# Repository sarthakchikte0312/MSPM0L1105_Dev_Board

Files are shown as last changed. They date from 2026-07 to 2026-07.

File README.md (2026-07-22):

# MSPM0L1105 Dev Board

A custom development/breakout board for Texas Instruments' **MSPM0L1105**, an ultra-low-power Arm Cortex-M0+ microcontroller. Designed in KiCad.

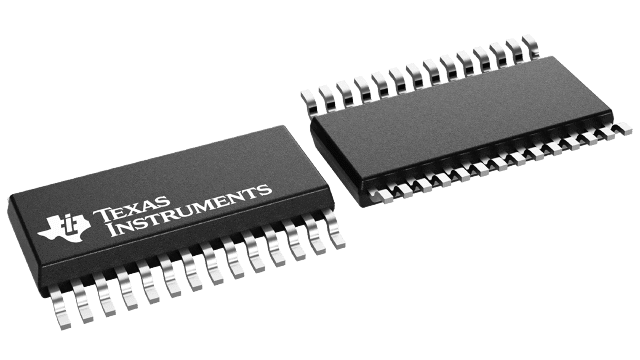
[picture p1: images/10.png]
PCB Render


## Why the MSPM0L1105?

The MSPM0L1105 is part of TI's MSPM0 family, and it's a solid choice for low-power, cost-sensitive embedded designs for a few reasons:

- **Arm Cortex-M0+ core** running up to 32 MHz — enough headroom for real control/sensor tasks while keeping power draw low.
- **Ultra-low-power modes** with fast wake-up, making it well suited for battery-powered or energy-harvesting applications.
- **Integrated analog peripherals** — 12-bit ADC, comparators, and op-amp(s) on many variants — reducing the need for external analog front-end components.
- **Rich communication peripherals** — UART, I2C, SPI — for interfacing sensors, displays, or other MCUs.
- **Low cost and small footprint**, making it attractive for space-constrained or high-volume designs where a full Cortex-M4 is overkill.
- **Common tooling** — MSPM0 shares a peripheral driver library (DriverLib) and code examples across the family, so firmware written here can port to bigger MSPM0 parts (M4-based) with minimal changes if the project scales up.
- Backed by TI's **SysConfig** tool, which simplifies pin muxing and peripheral configuration compared to hand-rolling register setup.

This dev board exists to make it easy to bring up, test, and prototype around the MSPM0L1105 — breaking out its I/O, providing power regulation, and exposing debug headers — before committing the MCU to a larger system design.


```
## Repository Structure

```
mspm0l1105-dev-board/
├── hardware/       KiCad project, schematic, PCB layout, libraries, 3D models
├── docs/           Datasheet, schematic PDF, pinout reference, BOM
├── images/         Board renders and photos
```

## Hardware Overview

| Item | Details |
|---|---|
| MCU | TI MSPM0L1105TDGS28R (Arm Cortex-M0+), VSSOP-28 package |
| Design tool | KiCad 10 |
| Layers | 2-layer, 1.6 mm board thickness |
| Board size | ~124 x 89 mm |
| Power in | USB-C receptacle (J4, USB4085) |
| Regulation | MIC5209-3.3YS LDO (U4) → 3.3V rail, selectable via LDO_JUMPER (J6) |
| USB-to-Serial | CH340K bridge (U2), for UART programming/debug over USB |
| Protection | SRV05-4 TVS array (U3) on USB D+/D− for ESD protection |
| Programming | BSL entry circuit (BSL_TX / BSL_RX / BSL_INVOKE) via Q3 (BC857) + D5/D6 (BAS16), auto-triggered from the USB-serial bridge's DTR/RTS lines |
| Debug | Dedicated 5-pin SWD header (J5): SWDIO / SWCLK / RST |
| Jumpers | J3 (UART-SELECT, 2x5), J6 (LDO_JUMPER), J7 (GND_JUMPER) |
| User I/O | SW1 = RESET, SW2 = BSL_BOOT, SW3 = USER (tied to PA16); D1 = green LED, D2 = blue LED, D4 = red LED |
| I/O broken out | J1 (IO_A) and J2 (IO_B), two 12-pin headers exposing UART0 (TXD/RXD), I2C (SCL/SDA), SPI (SCK/MOSI/MISO/CS1/CS2), TIMG4 capture pins, and GPIOs PA9/PA14/PA15/PA16/PA21/PA25/PA26/PA27 |
| Connectors | J1–J7: two GPIO headers, UART-select header, USB-C, SWD header, LDO and GND jumpers |

Full parts list with values and footprints: [`docs/BOM.csv`](docs/BOM.csv) (58 line items).

## Gerbers / Fabrication Output

This repo was built in **KiCad 10**. To (re)generate fab output, run from the `hardware/` folder with KiCad 9+ installed:

```bash
kicad-cli pcb export gerbers --output ../gerbers/ MSPM0L1105_dev_board.kicad_pcb
kicad-cli pcb export drill   --output ../gerbers/ MSPM0L1105_dev_board.kicad_pcb
```

Then zip the contents of `gerbers/` and upload directly to your fab house (JLCPCB, PCBWay, etc.). If you want, run these locally and drop the output in `gerbers/` before pushing — this sandbox only has KiCad 7 available, which can't open KiCad 10 project files, so it can't generate them for you.

## Getting Started

1. Clone this repo.
2. Open `hardware/MSPM0L1105_dev_board.kicad_pro` in KiCad (version *X.X* or later recommended).
3. Gerbers for the current revision are in `gerbers/` — ready to send to a fab house (JLCPCB, PCBWay, etc.).
4. See `docs/BOM.csv` for the parts list.

## Status

✅ Schematic and PCB layout complete (KiCad 10). Gerbers pending local export (see above) before sending to fab.

## Acknowledgements

- [TI MSPM0L1105 product page](https://www.ti.com/product/MSPM0L1105) for datasheet and reference material.

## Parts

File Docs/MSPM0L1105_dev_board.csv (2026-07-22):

Reference | Value | Footprint | Datasheet | Qty | DNP | Exclude from BOM | Exclude from Board
C1 | 0.47u | User_Global_Library:Cap-Tant-T491A |  | 1
C2 | 10n | Capacitor_SMD:C_0805_2012Metric_Pad1.18x1.45mm_HandSolder |  | 1
C3,C6,C7 | 100n | Capacitor_SMD:C_0805_2012Metric_Pad1.18x1.45mm_HandSolder |  | 3
C4,C8,C9 | 10u | User_Global_Library:Cap-Tant-CaseB |  | 3
C5 | 10n | Capacitor_SMD:C_1210_3225Metric_Pad1.33x2.70mm_HandSolder |  | 1
D1 | GREEN | User_Global_Library:LED_0603_or_0805 |  | 1
D2 | BLUE | User_Global_Library:LED_0603_or_0805 |  | 1
D3 | 1N4001W | User_Global_Library:D_SOD-123-pins12 |  | 1
D4 | RED | User_Global_Library:LED_0603_or_0805 |  | 1
D5,D6 | BAS16 | User_Global_Library:SOT-23-NEW |  | 2
J1 | IO_A | User_Global_Library:PinHeader_1x12_P2.54mm_Vertical |  | 1
J2 | IO_B | User_Global_Library:PinHeader_1x12_P2.54mm_Vertical |  | 1
J3 | UART-SELECT | User_Global_Library:PinHeader_2x5 |  | 1
J4 | USB_C_Receptacle_USB4085 | Connector_USB:USB_C_Receptacle_GCT_USB4085 | https://gct.co/connector/usb4085 | 1
J5 | SWD | User_Global_Library:PinHeader_1x05_P2.54mm_Vertical |  | 1
J6 | LDO_JUMPER | User_Global_Library:PinHeader_1x02_P2.54mm_Vertical |  | 1
J7 | GND_JUMPER | User_Global_Library:PinHeader_1x02_P2.54mm_Vertical |  | 1
Q3 | BC857 | User_Global_Library:SOT-23-NEW |  | 1
R1 | 100k 0.1% | Resistor_SMD:R_0805_2012Metric_Pad1.20x1.40mm_HandSolder |  | 1
R2,R3,R12 | 100R | Resistor_SMD:R_0805_2012Metric_Pad1.20x1.40mm_HandSolder |  | 3
R4,R5,R7,R17 | 100k | Resistor_SMD:R_0805_2012Metric_Pad1.20x1.40mm_HandSolder |  | 4
R8,R9,R25,R26,R27 | 10k | Resistor_SMD:R_0805_2012Metric_Pad1.20x1.40mm_HandSolder |  | 5
R10 | 220R | Resistor_SMD:R_0805_2012Metric_Pad1.20x1.40mm_HandSolder |  | 1
R11 | 820R | Resistor_SMD:R_0805_2012Metric_Pad1.20x1.40mm_HandSolder |  | 1
R13 | 1M | Resistor_SMD:R_1210_3225Metric_Pad1.30x2.65mm_HandSolder |  | 1
R14,R15 | 5.1k | Resistor_SMD:R_0805_2012Metric_Pad1.20x1.40mm_HandSolder |  | 2
R19 | 1k | Resistor_SMD:R_0805_2012Metric_Pad1.20x1.40mm_HandSolder |  | 1
R24 | 47k | Resistor_SMD:R_0805_2012Metric_Pad1.20x1.40mm_HandSolder |  | 1
SW1 | RESET | User_Global_Library:Tact-SW-4x3mm-body |  | 1
SW2 | BSL_BOOT | User_Global_Library:Tact-SW-4x3mm-body |  | 1
SW3 | USER_PA16 | User_Global_Library:Tact-SW-4x3mm-body |  | 1
U1 | MSPM0L1105TDGS28R | User_Global_Library:VSSOP28-DGS-TI |  | 1
U2 | CH340K | User_Global_Library:SSOP-10-1EP_CH340K |  | 1
U3 | SRV05-4 | User_Global_Library:SOT23-6 | http://www.onsemi.com/pub/Collateral/SRV05-4-D.PDF | 1
U4 | MIC5209-3.3YS | User_Global_Library:SOT-223 |  | 1

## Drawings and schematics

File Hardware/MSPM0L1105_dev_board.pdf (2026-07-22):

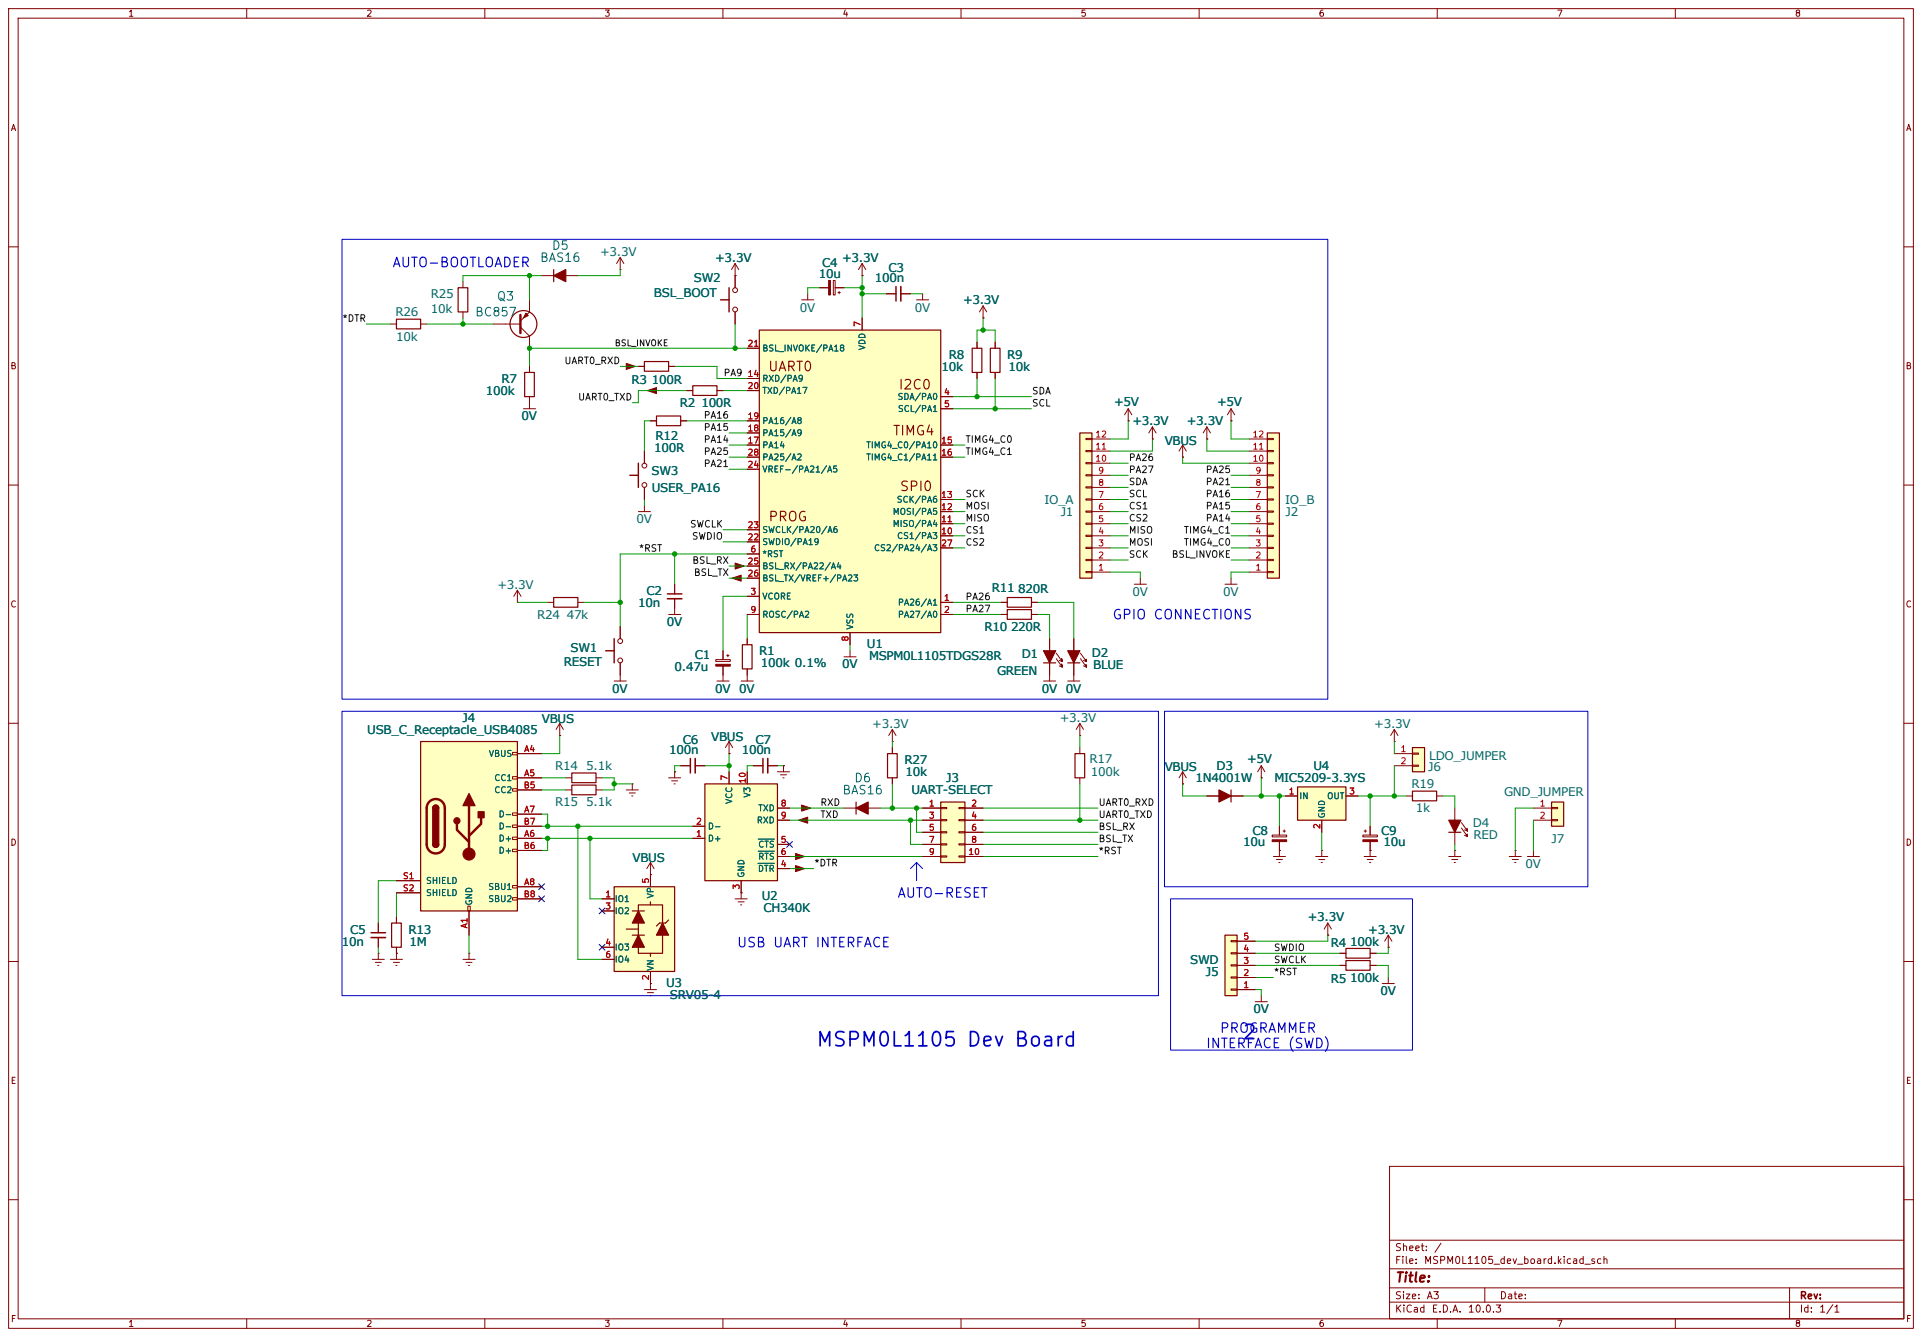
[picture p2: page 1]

3 DTR 4 CTS 5 RTS 6 VCC

SHIELD S1

Size: A3 | Rev: | F Date:
KiCad E.D.A. 10.0.3 | Id: 1/1

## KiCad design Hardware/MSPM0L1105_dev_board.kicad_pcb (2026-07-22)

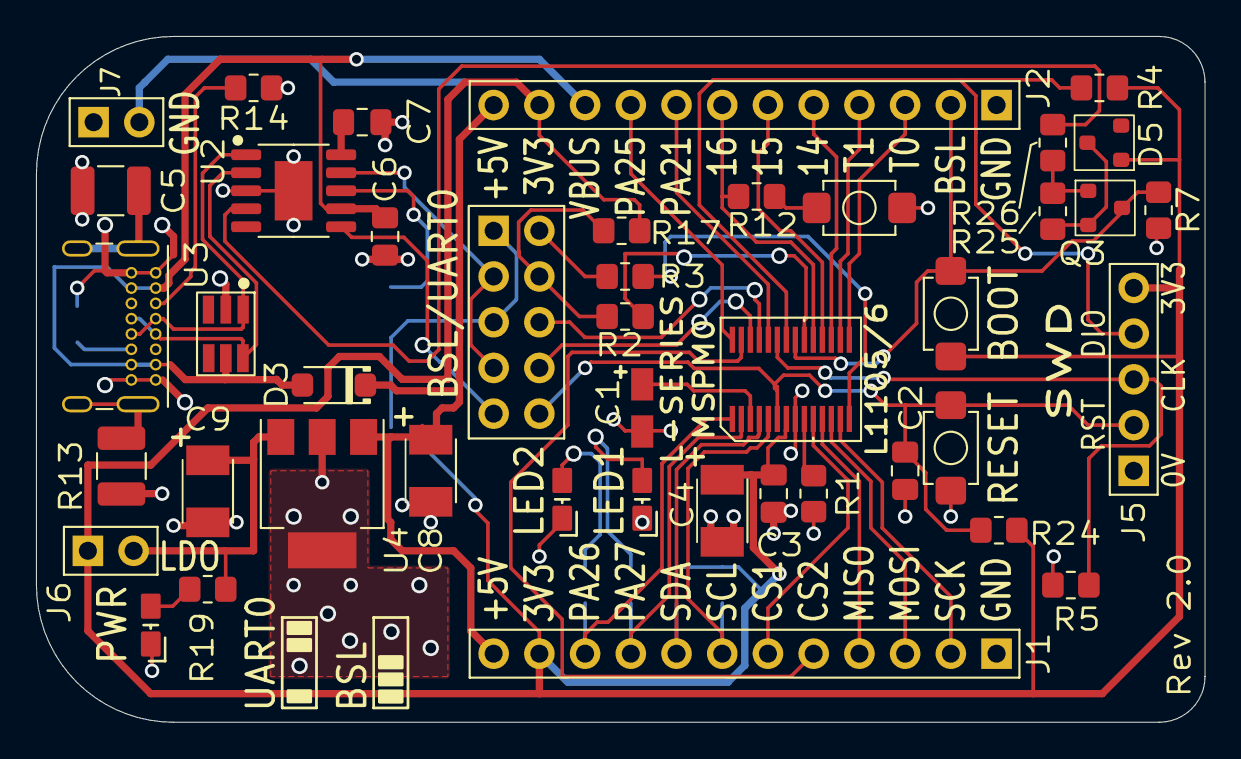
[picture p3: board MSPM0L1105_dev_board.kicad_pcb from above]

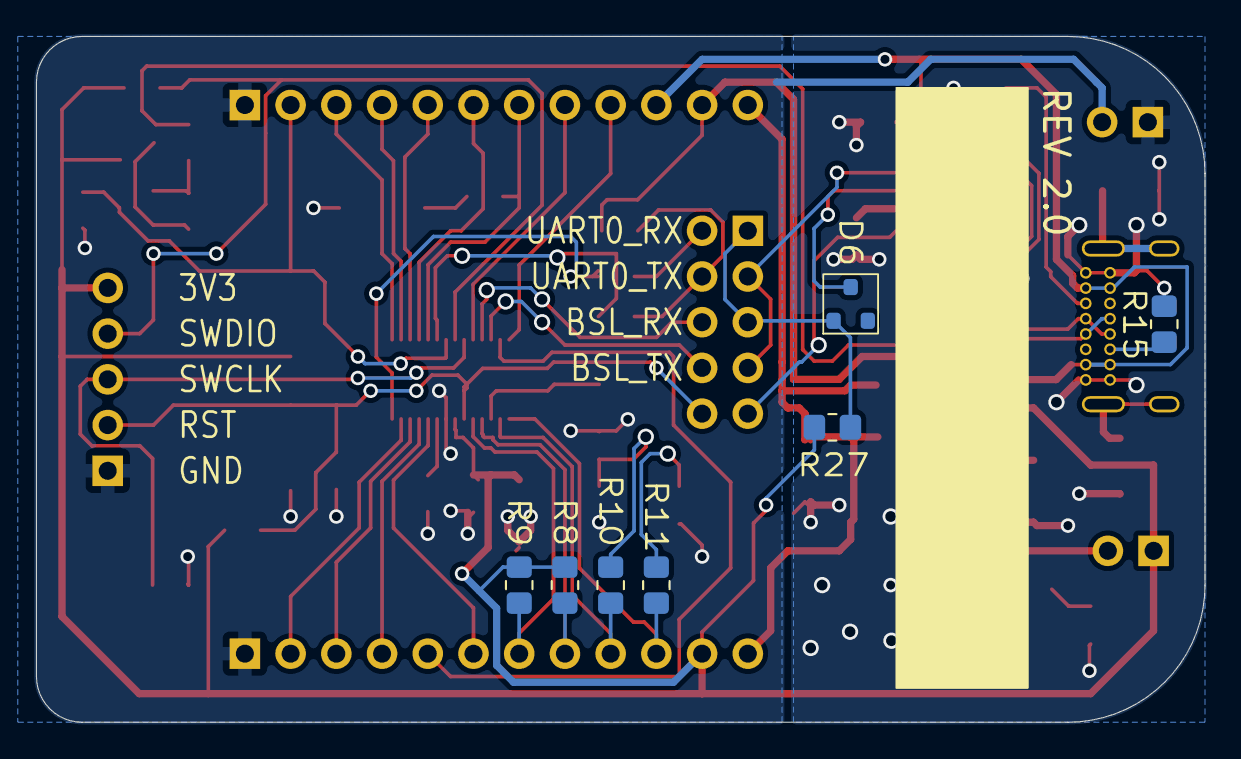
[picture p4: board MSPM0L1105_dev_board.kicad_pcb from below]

Board: 2 copper layers, 64.9 x 38.1 mm, 50 parts (7 on the bottom side), 52 nets.

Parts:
C1: 0.47u; Cap-Tant-T491A
C2: 10n; C_0805_2012Metric_Pad1.18x1.45mm_HandSolder
C3, C6, C7: 100n; C_0805_2012Metric_Pad1.18x1.45mm_HandSolder
C4, C8, C9: 10u; Cap-Tant-CaseB
C5: 10n; C_1210_3225Metric_Pad1.33x2.70mm_HandSolder
D1: GREEN; LED_0603_or_0805
D2: BLUE; LED_0603_or_0805
D3: 1N4001W; D_SOD-123-pins12
D4: RED; LED_0603_or_0805
D5, D6: BAS16; SOT-23-NEW
J1: IO_A; PinHeader_1x12_P2.54mm_Vertical
J2: IO_B; PinHeader_1x12_P2.54mm_Vertical
J3: UART-SELECT; PinHeader_2x5
J4: USB_C_Receptacle_USB4085; USB_C_Receptacle_GCT_USB4085_improved
J5: SWD; PinHeader_1x05_P2.54mm_Vertical
J6: LDO_JUMPER; PinHeader_1x02_P2.54mm_Vertical
J7: GND_JUMPER; PinHeader_1x02_P2.54mm_Vertical
Q3: BC857; SOT-23-NEW
R1: 100k 0.1%; R_0805_2012Metric_Pad1.20x1.40mm_HandSolder
R2, R3, R12: 100R; R_0805_2012Metric_Pad1.20x1.40mm_HandSolder
R4, R5, R7, R17: 100k; R_0805_2012Metric_Pad1.20x1.40mm_HandSolder
R8, R9, R25, R26, R27: 10k; R_0805_2012Metric_Pad1.20x1.40mm_HandSolder
R10: 220R; R_0805_2012Metric_Pad1.20x1.40mm_HandSolder
R11: 820R; R_0805_2012Metric_Pad1.20x1.40mm_HandSolder
R13: 1M; R_1210_3225Metric_Pad1.30x2.65mm_HandSolder
R14, R15: 5.1k; R_0805_2012Metric_Pad1.20x1.40mm_HandSolder
R19: 1k; R_0805_2012Metric_Pad1.20x1.40mm_HandSolder
R24: 47k; R_0805_2012Metric_Pad1.20x1.40mm_HandSolder
SW1: RESET; Tact-SW-4x3mm-body
SW2: BSL_BOOT; Tact-SW-4x3mm-body
SW3: USER_PA16; Tact-SW-4x3mm-body
U1: MSPM0L1105TDGS28R; VSSOP28-DGS-TI
U2: CH340K; SSOP-10-1EP_CH340K
U3: SRV05-4; SOT23-6
U4: MIC5209-3.3YS; SOT-223

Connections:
0V: C1.2, C2.2, C3.2, C4.2, D1.1 (K), D2.1 (K), J1.1, J2.1, J5.1, J7.2, R1.2, R5.2, R7.2, SW1.1, SW3.1, U1.8 (VSS)
+3.3V: C3.1, C4.1, D5.1 (A), J1.11, J2.11, J5.5, J6.1, R4.2, R8.1, R9.1, R17.1, R24.1, R27.1, SW2.2, U1.7 (VDD)
+5V: C8.1, D3.1 (K), J1.12, J2.12, U4.1 (IN)
/*DTR: R26.1, U2.4 (~DTR)
/*RST: C2.1, J3.10, J5.2, R24.2, SW1.2, U1.6 (*RST)
/BSL_INVOKE: J2.2, Q3.3 (C), R7.1, SW2.1, U1.21 (BSL_INVOKE/PA18)
/BSL_RX: J3.6, U1.25 (BSL_RX/PA22/A4)
/BSL_TX: J3.8, U1.26 (BSL_TX/VREF+/PA23)
/CS1: J1.6, U1.10 (CS1/PA3)
/CS2: J1.5, U1.27 (CS2/PA24/A3)
/MISO: J1.4, U1.11 (MISO/PA4)
/MOSI: J1.3, U1.12 (MOSI/PA5)
/PA9: R3.2, U1.14 (RXD/PA9)
/PA14: J2.5, U1.17 (PA14)
/PA15: J2.6, U1.18 (PA15/A9)
/PA16: J2.7, R12.2, U1.19 (PA16/A8)
/PA21: J2.8, U1.24 (VREF-/PA21/A5)
/PA25: J2.9, U1.28 (PA25/A2)
/PA26: J1.10, R11.1, U1.1 (PA26/A1)
/PA27: J1.9, R10.1, U1.2 (PA27/A0)
/RXD: D6.3 (K), U2.8 (TXD)
/SCK: J1.2, U1.13 (SCK/PA6)
/SCL: J1.7, R9.2, U1.5 (SCL/PA1)
/SDA: J1.8, R8.2, U1.4 (SDA/PA0)
/SWCLK: J5.3, R5.1, U1.23 (SWCLK/PA20/A6)
/SWDIO: J5.4, R4.1, U1.22 (SWDIO/PA19)
/TIMG4_C0: J2.3, U1.15 (TIMG4_C0/PA10)
/TIMG4_C1: J2.4, U1.16 (TIMG4_C1/PA11)
/TXD: J3.3, J3.7, U2.9 (RXD)
/UART0_RXD: J3.2, R3.1
/UART0_TXD: J3.4, R2.1, R17.2
Earth: C5.2, C6.1, C7.2, C8.2, C9.2, D4.1 (K), J4.A1 (GND), J4.A12 (GND), J4.B1 (GND), J4.B12 (GND), J7.1, R13.2, R14.2, R15.2, U2.3 (GND), U2.11 (GND), U3.2 (VN), U4.2 (GND)
unnamed: C5.1, J4.S1 (SHIELD)
unnamed: D1.2 (A), R10.2
unnamed: D2.2 (A), R11.2
unnamed: D4.2 (A), R19.2
unnamed: D5.3 (K), Q3.2 (E), R25.1
unnamed: D6.1 (A), J3.1, J3.5, R27.2
unnamed: J3.9, U2.6 (~RTS)
unnamed: J4.A5 (CC1), R14.1
unnamed: J4.B5 (CC2), R15.1
unnamed: J4.S2 (SHIELD), R13.1
unnamed: C9.1, J6.2, R19.1, U4.3 (OUT)
unnamed: Q3.1 (B), R25.2, R26.2
unnamed: R12.1, SW3.2
unnamed: R1.1, U1.9 (ROSC/PA2)
unnamed: R2.2, U1.20 (TXD/PA17)
unnamed: C1.1, U1.3 (VCORE)
unnamed: J4.A6 (D+), J4.B6 (D+), U2.1 (D+), U3.1 (IO1)
unnamed: J4.A7 (D-), J4.B7 (D-), U2.2 (D-), U3.6 (IO4)
unnamed: C7.1, U2.10 (V3)
VBUS: C6.2, D3.2 (A), J2.10, J4.A4 (VBUS), J4.A9 (VBUS), J4.B4 (VBUS), J4.B9 (VBUS), U2.7 (VCC), U3.5 (VP)
